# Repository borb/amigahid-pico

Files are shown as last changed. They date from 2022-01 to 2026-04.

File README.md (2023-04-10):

# amigahid-pico

please note: the interesting stuff goes into the [development](https://github.com/borb/amigahid-pico/tree/development) branch, so if main seems slow, check it out.

## introduction

amigahid-pico uses the rp2040 microcontroller (e.g. the raspberry pi pico) in a carrier board to attach usb input devices to a standard amiga without the need for a usb stack on the amiga itself.

it currently supports keyboards and mice and provides connection via the internal keyboard connector, the rj11/din socket on big-box amigas, and via the controller ports.

**this project is very much a work in progress.**

## **important note**

* current kicad files are for r5 pcb, pin mappings are not yet in the source tree! i have not yet generated this board as a pcb, but it is mostly identical to r4. the keyboard and controller port 1 are correct at time of writing, and will be fixed for the second controller port when the next prototype arrives.

* **always read the [errata](./doc/errata.md) section for the current pcb layout before deciding whether or not to build.**

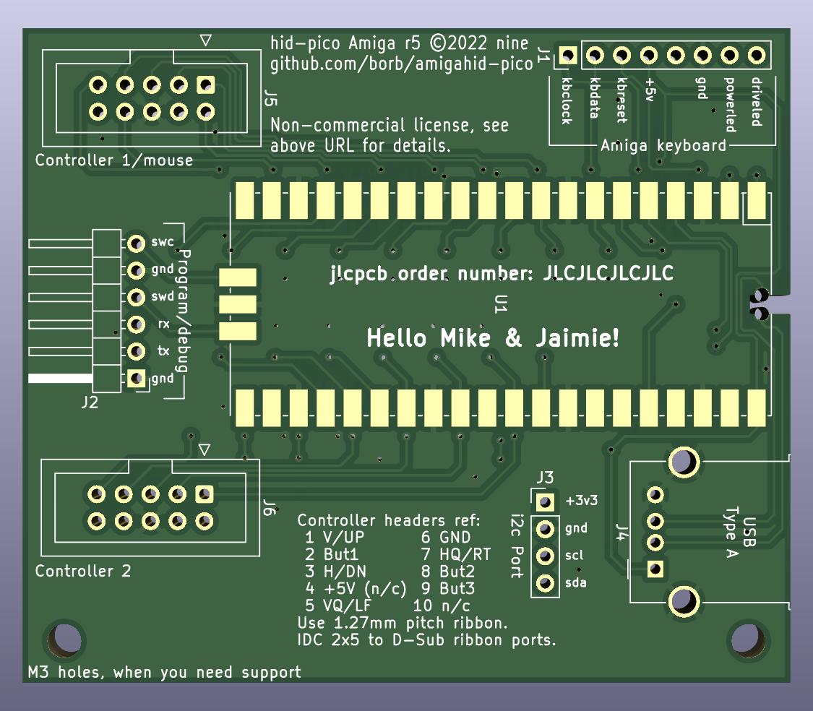
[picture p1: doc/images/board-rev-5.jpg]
rev 5 pcb


## documentation

* [installation](./doc/installation.md)
* [hardware](./doc/hardware.md)
* [errors in revisions (errata)](./doc/errata.md)

## history

this project is a rewrite of the [amigahid](https://github.com/borb/amigahid) project to the rp2040 microcontroller.

originally, after the retirement of the arduino adk board and shortening availability of the max3421e "usb host shield" for arduino boards, the need for a cheap, easy and continually available replacement was sought.

at first, the uhs mini via a level shifter seemed ideal, but significant issues were found convincing it to work with a variety of arduino boards.

the rp2040 made sense as a target because it is widely available, has sufficient physical connections and is powerful enough to meet multiple needs.

## what is the latency of this?

i have not measured the latency, but the keyboard signals are sent out the moment they are received on the usb bus. the potential latency is likely fractionally longer than the amiga mcu but bear in mind the rp2040 is significantly faster than the standard amiga keyboard controller.

## roadmap

please see the issues tab on the [github repository](https://github.com/borb/amigahid-pico) for the current list of planned features. the tl;dr is:

normal:
* i<sup>2</sup>c display for config/status
* controller emulation
    * keyboard-based controller emulation (use udlr for directions?)
* flash memory-based configuration
* possible amiga-side control panel (using bidirectional controller port signals)
* rotary control simulation (for controlling gotek drives)

crazy talk:
* non-amiga support
* non-hidbp support
* analogue/paddle emulation
* fix some tinyusb issues (hotplug, timing-related instability)

## license

on the fence at the moment, but the current license choice is Eclipse Public License 2.0 (EPL-2.0).

## third party licenses

* µgui: this code contains 'µgui' by achim döbler; the license for this can be read at in the [display readme](./src/display/README.md)

## whuh... who?

nine <[nine@aphlor.org](mailto:nine@aphlor.org)>

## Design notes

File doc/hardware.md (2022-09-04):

# hardware

## how do i attach this to my amiga?

### a500

the standard board is designed to be mounted atop the amiga 500 keyboard header. mount a strip of eight 2.54mm pitch sockets with sufficient clearance from the nearby custom chips (cia, mostly). the drill holes are m3 - use some nylon supports to support the board and stop it flexing.

for other amigas, you will need to refer to your model's keyboard socket. instead of a socket on the underside, mount 2.54mm pitch idc pin strip to the top of the board and use dupont connections to attach to the amiga in your favoured manner. most amigas except for the a1000 (which uses an rj11 connector) use some form of din plug. the signalling is identical across the entire range.

the pcb has a key for signals; only kclk, kdat, power and ground are required. reset is not required for big-box amigas, which use clock to signal reset.

### a600/a1200

the amiga 600 and 1200 have a surface mounted keyboard mcu; until a design has been put together, you can tap kclk, kdat and reset from the chip (use an upturned plcc socket). find the pin information at [amigapcb.org](https://www.amigapcb.org/). please be **really** careful attaching to these machines.

attach these lines to the standard amigahid-pico header in the correct position.

### a1000/a2000/a3000/a4000/cdtv/cd32

the din socket (rj11 on the a1000) for these models should map the +5v, kclk and kdat. these models do not have a reset signal, instead they rely on holding kclk low for a period to signal the hard reset signal to the amiga.

map these pins to the corresponding signals on the a500 keyboard header on the amigahid-pico pcb.

## amiga 500 keyboard header

all signals are active low.

| pin# | signal | meaning  | notes |
|---|---|---|---|
| 1 | kclk | clock | |
| 2 | kdat | data | |
| 3 | /res | reset | issues a hard reset |
| 4 | +5v | 5v power | |
| 5 | nc | nc | not connected (often physically absent) |
| 6 | gnd | ground | though if powering arduino/avr from psu, may be able to use that ground line |
| 7 | pwr | power | provides power to keyboard power led to indicate amiga is on/audio filter status |
| 8 | drv | drive | indicates floppy drive activity |

7 and 8 are not connected to the pico in any way, so you may want to investigate another way of indicating floppy drive and power status.

## what about controllers?

please see the silkscreen for the short-term connection notes. the wiring guide is detailed there for simplicity.

using 2.54mm pitch idc pin plug (female type), insert 9 strands of 1.25mm pitch ribbon cable, aligning to pin one of the connector (usually with a red stripe on the ribbon), pressing with a vise or suitable ribbon cabling tool. using a ribbon-type d-sub, align pin 1 of the ribbon to pin 1 of the d-sub, and complete the attachment using the vise/ribbon cabling tool.

whilst the idc header has an interleave meaning the ribbon is ordered incrementally (1-2-3-4-5-6-7-8-9), the d-sub ribbon ordering goes 1-6-2-7-3-8-4-9-5; this is compensated for by the board design.

if you have a r2 pcb, i'm very sorry, you'll need to read the silkscreen and build a custom attachment, likely from dupont pins. i would strongly suggest switching to r4 or later.

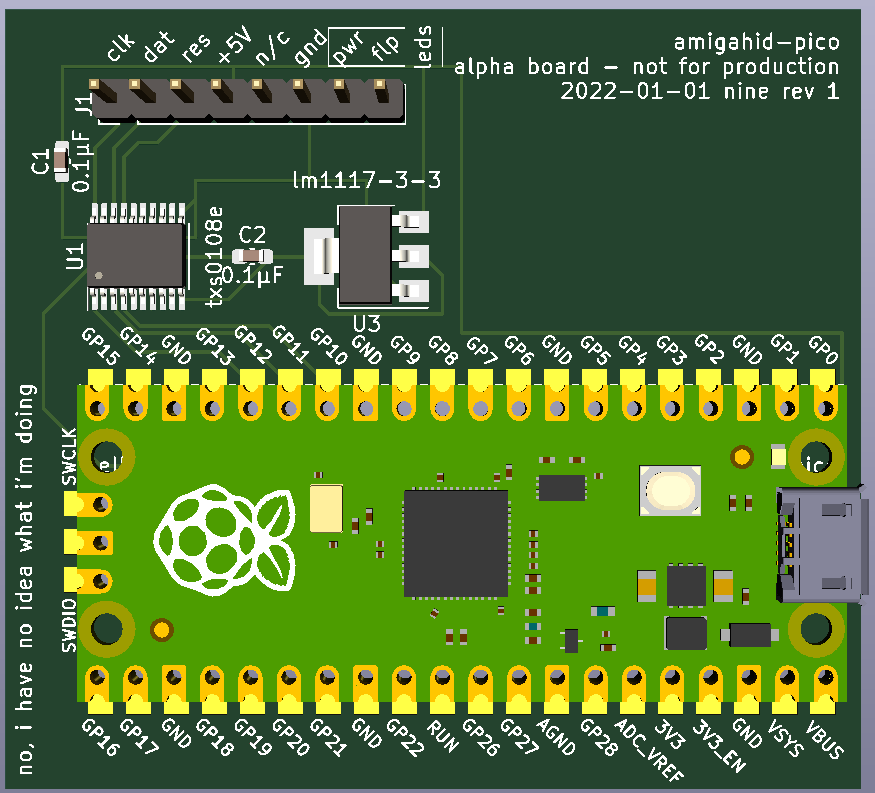
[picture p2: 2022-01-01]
doc/images/board-alpha-rev-1.png

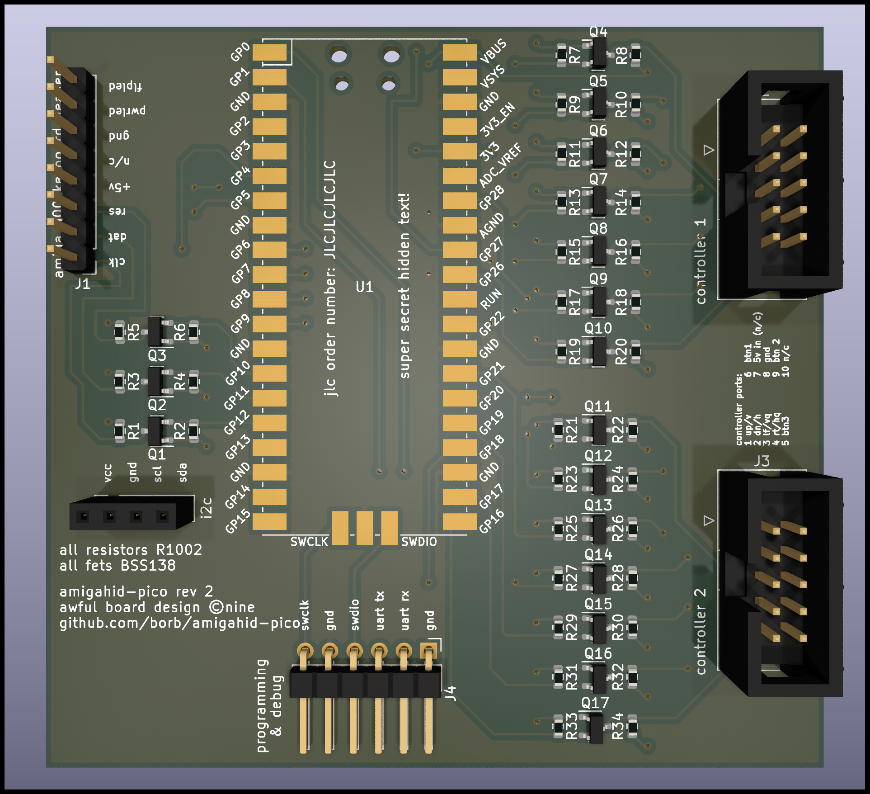
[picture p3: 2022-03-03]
doc/images/board-rev-2.png

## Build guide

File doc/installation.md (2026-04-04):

# installation

## configuration

the file [CMakeLists.txt](/CMakeLists.txt) has a small number of configuration options. the critical aspects of the build can be specified on the `cmake` commandline; you should not normally need to edit the [CMakeLists.txt](/CMakeLists.txt) file unless you are doing something outlandish.

## building the source code

prior to installation, ensure you have cmake, gnu make and gcc targetted to arm-none-eabi. you should be able to find these in debian. homebrew in macos has a cask for prebuilt gcc 10 binaries from arm. under windows, you're probably best off using wsl.

clone the repository. once cloned, you'll need to initialise the submodule for the pico sdk.

```shell
$ git submodule update --init --recursive
```

the tinyusb component of the pico-sdk has a lot of its own submodules so this could take some time.

when it's ready, start cmake off; you'll need to specify the board type you're using. if you omit it, you'll get a build for the default target, amigahid-pico standard pcb revision 4. this is akin to running:

```shell
$ cmake -B build/ -S . -DBOARD_TYPE=BOARD_HIDPICO_REV4
```

but you can also run this to get a revision 2 pcb build (the pin assignments are different):

```shell
$ cmake -B build/ -S . -DBOARD_TYPE=BOARD_HIDPICO_REV2
```

at present there are only two targets, revision 2 and revision 4. revision 3 users should not use the pcb as it has a faulty pin assignment which can spontaneously reset the rp2040 controller, so please do not use it.

you can also enable generation of debug symbols so as to use `openocd` and `gdb` to debug a running target over serial-wire debug (swd). to do this, add the parameter `-DCMAKE_BUILD_TYPE=Debug`, e.g.:

```shell
$ cmake -B build/ -S . -DBOARD_TYPE=BOARD_HIDPICO_REV4 -DCMAKE_BUILD_TYPE=Debug
```

a 'Release' build is generated by default.

then build:

```shell
$ cd build && cmake --build build/
```

see next section for installing on a pico.

## installing on a pi pico (or similar) board

for the simplest option, pick usb. swd is good for remote debugging and reprogramming without detaching devices.

### usb (bootsel)

take a powered down pico, hold the bootsel button and attach a micro usb cable. copy the `amigahid-pico.uf2` file from `build/src/` to the mounted usb storage volume. the pico will spontaneously disconnect, and when it comes back, it will be running the amigahid-pico code. disconnect usb and attach an otg adapter.

### serial wire debug (swd)

swd uses openocd to program the flash memory attached to the rp2040.

to use swd to install the firmware, see chapter 5 of [getting started with raspberry pi pico](https://datasheets.raspberrypi.com/pico/getting-started-with-pico.pdf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).

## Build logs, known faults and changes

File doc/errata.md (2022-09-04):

# errata

this project is still in the relatively early stages in terms of hardware design and i'm learning things like kicad as i go along. it's likely i'll make mistakes, so this section documents those mistakes.

## board revision 1

revision 1 was based around using the txs0108 bidirectional level shifter, which proved to be a mistake: whilst it worked for keyboard functionality, the voltage drop once connected to a controller port was so significant the amiga was held in reset. this would not have been an issue for big-box amigas as they have no dedicated reset line on the keyboard port, but it would have proved difficult for the amiga 500, 600 and 1200.

## board revision 2

revision 2 of the board was the first successful test. this will change in the near future as some quirks were discovered during assembly. the design was changed to be mosfet-centric using the bss138; this may change in future. long-term, i'd like to use an ic rather than a series of (at present) 17 mosfets, but i have not yet found a part which provides all of the desired features.

the pico is attached using castellated edges to pads on the surface. ensure the alignment is straight and flood the edges with solder, ensuring the solder makes contact with both the edge and the pad (check). buzz the attachment out with a multimeter to ensure it's worked and not shorted.

for the amiga 500, the keyboard connector can use 2.54mm pitch sockets on the seven pin header and attach directly to the motherboard, though for simplicity of placement you may want to use short dupont wires for attachment.

the programming & debug header provides serial wire debug and uart connections. you can program either via swdio or the usb port & bootsel button.

the four pin i<sup>2</sup>c header is suitable for the generally available ssd1306 displays to mount directly to, assuming the pin layout is identical. the display is not currently used but will be used in future versions.

attach a usb otg adapter to the pico's usb port. usb hubs are supported, but only at a single level. multiple mice and keyboards can be attached and used concurrently, allowing you to attach a keyboard for desk and one for remote usage (e.g. sofa).

the controller ports mapping will change after revision 2: the assumption was made that 2x5 pin idc connectors were wired the same way as d-sub 9-pin connectors, and this was wrong. the numerical wiring works 1-2-3-4-5-6-7-8-9 vs 1-6-2-7-3-8-4-9-5, making ribbon attachment difficult in revision 2. this will be changed in revision 3.

## board revision 3 (not in version control)

was a reworking of revision two but with the intention of being smaller and introducing a castellated edge for attaching to the usb test pads; this version was never put into version control and has the same idc numbering problem as revision 2.

## board revision 4

warning: don't build this version; it's just for testing.

sticking with the mosfet design, this version fixes the idc to d-sub pin wiring so a flat 1.27mm pitch can be used.

downside: there are vias beneath the pico's keepouts for the bootsel/ground/power test points. if your board manufacturer doesn't coat the vias with solder mask sufficiently then these could make contact with the test points. if this happens, either use some polyamide (kapton) tape or clear nail varnish to insulate the test points before mounting the pico.

erroneously, pin 30 (run) was attached as the horizontal/down line on the second controller port. as a result, h/down has been moved to 31, and v/up has been moved to 32 on revision 5.

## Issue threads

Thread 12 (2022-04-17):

Amiga configuration preference panel

borb, 2022-04-17:
Not yet sure if this makes sense if using i<sup>2</sup>c display (issue #5) and runtime configuration via keyboard hotkey (issue #6).

Gist is, button 1/2/3 are bidirectional pins on the Amiga side (they do go through a 74LS157 two-to-one line multiplexer), but can be used for bidirectional communication. Would need some form of attention-signal detection before beginning communication.

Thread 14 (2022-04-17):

Gotek control

borb, 2022-04-17:
As title suggests; control the Gotek navigation from the keyboard. USB HID has keys the Amiga does not, so this should be fairly possible.

i<sup>2</sup>c should be possible, or send pulses à la the rotary encoder mechanism. i<sup>2</sup>c would piggyback off of the display port but may have issues on Gotek-side with any displays attached there (or displays on the hid-pico side snatched by the Gotek). Rotary encoder pulses likely a safer mechanism.

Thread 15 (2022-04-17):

Send Amiga reset warning

borb, 2022-04-17:
I've pondered this for a while. I know that this behaviour is discrepant between Amiga models (Linux on my A1200 used to moan about it when ctrl-a-a was pressed). I don't actually know if the Amiga handles this; I've never probed the Kickstart ROM to work out it out. Can the 6502 code be read off of the keyboard MCU? That would be useful but I doubt it (most microcontrollers employ anti-theft mechanisms to prevent code being lifted from a device once programmed). I also don't have the kit for that.

However.

Anecdotally, dev docs refer to sending a reset warning keycode to the Amiga in order to get it to shore up its business before reset is asserted. If the reset warning isn't acknowledged, it's assumed the Amiga has gone to lunch and the reset pin (or clock low hold) is employed after a delay to ensure that the reset actually happens. This _should_ give the Amiga time to sync any filesystem buffers to disk before a reset occurs.

I don't actually know if in AmigaOS this ever occurs.

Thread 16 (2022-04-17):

Mouse wheel codes via keyboard interface

borb, 2022-04-17:
Wheel up/wheel down can be sent to the Amiga. OS 3.1 had support for this in the AmigaGuide renderer for Multiview, which is useful as a test. The codes are referred to as "NewMouse" standard [from the serial mouse driver in Aminet](https://aminet.net/package/driver/input/NewMouse12). I assume the codes were already referred to in a document somewhere prior to NewMouse implementing them. Because these codes reside above $80, they only need a single event transmission and not the typical down/up event of a keystroke.

It's possible that the mouse may need some form of mode switch much like the PS/2 era mice did to put them into 3 or 4 byte packet mode. This has not been tested.

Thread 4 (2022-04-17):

Tracking USB hub support in TinyUSB

borb, 2022-04-17:
The root repository uses the pico-sdk assigned tag from upstream TinyUSB, but in my working tree I build against [Ryzee119's TinyUSB multi-hub branch](https://github.com/Ryzee119/tinyusb/tree/multi-hub) which is currently [in a pull request](https://github.com/hathach/tinyusb/pull/1290) for upstreaming.

tl;dr: to use this, likely transient, tree in hid-pico will mean having to fork pico-sdk to repoint at the multi-usb branch, and that's annoying and temporary.

Right now, this issue exists purely to track the inclusion of multi-hub in upstream TinyUSB.

borb, 2022-09-04:
The pico-sdk (1.4.0) has not imported 0.14.0 yet, which is important for fixes to mousehid motion being jerky and multilevel usb hub support.

As a result, we now load our own tinyusb. This is in main as of 9641b7586c963452d354f7d5ce13c67297ff7321. Closing.

Closed 2022-09-04.

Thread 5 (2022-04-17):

i2c display support

borb, 2022-04-17:
Add i<sup>2</sup>c display support. This will allow the user to:

* track device connection status
* see operation status
* debug/diagnose without serial at a glance
* access config menu (when added)

Current target is 128x64 SSD1306 display. Initial tests with some library code have proved unreliable, as the font was small but switching to a larger font caused rendering issues. Suggest porting the code from flashfloppy's stm32 target to the rp2040 i2c layer.

borb, 2022-10-31:
Completed.

Closed 2022-10-31.

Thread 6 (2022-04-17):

Runtime configuration

borb, 2022-04-17:
Add support to change configuration during runtime rather than at build time. It would be annoying to assemble, compile, deploy and fit a board only to find, for example, right-Amiga is mapped to right-GUI rather than menu since that would impede Amiga rebooting.

Add a menu (dependant on display) and store configuration in flash. Load that configuration on power up. Allow for config to be reset.

Depends on issue #5.

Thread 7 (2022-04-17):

USB Type A socket

borb, 2022-04-17:
Add a USB type A socket. This can be done by either:

* connecting to the micro-USB port and providing a type A socket; hacky but stable
* attaching to test points beneath the micro-USB socket and running to a type A socket

borb, 2022-04-17:
Added in revision 4 (see 65ffd97fab697f31d4ec6cc0d69d6c9d1e991e65). Awaiting PCB delivery to test.

borb, 2022-04-20:
Protos arrived today. Didn't specify castellated edges, but the finish is easily acceptable (the aperture is super tiny though, so this is either a hot air or tiny tip job. Had to trim some hanging via plating with a scalpel. Test pads line up ok, solder mask looks suitable. Think this might work ok.

Will assemble tomorrow.

borb, 2022-04-21:
Ok, it works.

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

I'm keeping it external whilst I probe around the pins to see what's firing where, but everything works. Still need to move the ground plane via, which is in the Pico's keepout area. But success.

rfuest, 2022-04-21:
Nice, the USB A connector looks so much better than an OTG adapter. I think I should build one.

borb, 2022-04-21:
> Nice, the USB A connector looks so much better than an OTG adapter. I think I should build one.

I have more boards than I am going to use in this production run. Would you like a couple of samples sent to you?

rfuest, 2022-04-21:
Thanks for the offer. I'm not sure where you are located, but unfortunately it's often cheaper to order new PCBs for China than paying postage for PCBs.

borb, 2022-04-21:
Socket is working. Closing.

Closed 2022-04-21.

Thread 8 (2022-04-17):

Make keyboard LEDs work

borb, 2022-04-17:
Keyboard LEDs don't seem to work. The code was tried but commented out as it plainly didn't work, and suspect it has been responsible for TinyUSB stack crashes.

borb, 2022-04-17:
@rfuest has addressed this in PR #2.

borb, 2022-04-18:
Merged, tested, cllosing.

Closed 2022-04-18.

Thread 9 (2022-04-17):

Watchdog timer

borb, 2022-04-17:
Employ use of a watchdog timer. If the usual event loop doesn't poke the timeout register, the whole shebang gets rebooted.

Add the ability to turn this off via configuration (#6) since it could be irritating.

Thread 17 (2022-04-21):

lcont2_h connected to RUN input

rfuest, 2022-04-21:
In the latest schematic revision the `lcont2_h` signal is connected to `RUN` input (pin 30) on the Pico. This would reset the Pico on mouse movement or when the joystick is pushed back.

borb, 2022-04-21:
🤦

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

I really should have spotted that.

borb, 2022-04-21:
Okay, it's not as bad as resetting the Pico: the Amiga would have to pull back, and that won't happen because it's an output only and the Amiga keeps it at 5V; hence the other side of the fet will still be held at 3.3V.

So it's just a completely useless pin. Will fix; another revision on the way 😄

rfuest, 2022-04-21:
I was confused when I opened the issue and somehow thought that the controller connections were inputs :confused:.

rfuest, 2022-04-21:
Can we decide how this should be fixed in the next revision. I would like to change this in the PCBs I order and don't want to create yet another pinout variant.

The two easiest options are:
* Move `lcont2_h` to pin 32
* Move `lcont2_v` to pin 32 and `lcont2_h` to pin 31

borb, 2022-04-21:
The second option makes the most sense to me, since the first would mean having to route the second controller H line through another via in order to get to the same pin on the IDC connector, whereas the second just moves the fet connectors up a level.

Alternatively, I could produce another version this evening (I need to go and put my children to bed first) and if it passes your visual inspection, go with that version?

borb, 2022-04-21:
Actually, looking at the pcb layout, I'll just change the top-side tracks from the vias to the pads; the vias can remain where they are for bottom-side simplicity, and the top side can move over.

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

And I'll fix this as well. And remember not to turn the visibility of User.Drawings off whilst placing vias in future.

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

rfuest, 2022-04-21:
> Alternatively, I could produce another version this evening (I need to go and put my children to bed first) and if it passes your visual inspection, go with that version?

I think I'll create my own version of the PCB. I want to rearrange the keyboard and joystick connectors to one side of the PCB. And I'll probably try to use a 4 layer PCB to make the power/ground routing a bit easier. By using a 4 layer PCB it's also possible to use a controlled impedance trace for the USB connection, which is probably not necessary for the short USB 1.1 run, but it makes me feel better :wink:.

borb, 2022-04-21:
> > Alternatively, I could produce another version this evening (I need to go and put my children to bed first) and if it passes your visual inspection, go with that version?
>
> I think I'll create my own version of the PCB. I want to rearrange the keyboard and joystick connectors to one side of the PCB. And I'll probably try to use a 4 layer PCB to make the power/ground routing a bit easier. By using a 4 layer PCB it's also possible to use a controlled impedance trace for the USB connection, which is probably not necessary for the short USB 1.1 run, but it makes me feel better 😉.

You sound like you know what you're doing 😄 Would very much appreciate seeing this done properly as well!

rfuest, 2022-04-21:
Have you decided on a license for the PCB project yet? To my very limited legal/licensing knowledge, the non commercial clause on the PCB doesn't match with the EPL mentioned in the README.

borb, 2022-04-21:
> Have you decided on a license for the PCB project yet? To my very limited legal/licensing knowledge, the non commercial clause on the PCB doesn't match with the EPL mentioned in the README.

My knowledge is limited in this area also.

All I particularly want to avoid is the swathes of overpriced stuff being sold at a markup on eBay and elsewhere, especially since this is a fairly simple board. I've seen some other projects of similar ilk selling for ridiculous prices so I want to avoid that happening here.

My typical go-to would be creative commons, non-commercial, sharealike with attribution.

Closed 2022-04-21.

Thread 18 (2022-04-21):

PCB issues

borb, 2022-04-21:
Two things:

- Fix typo - "commerical" should be "commercial"
- Move ground plane via out from beneath pico keepout

borb, 2022-04-21:
Fixed in last two commits.

Closed 2022-04-21.

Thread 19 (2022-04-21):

LED pins

rfuest, 2022-04-21:
The README states that the user must find some other ways to connect the pin 7 and pin 8 leds. IMO it would be useful to provide some option to use these signals. Here are some options to use them:
* Empty LED and resistor footprints on the PCB that can be populated if required
* A resistor on the board and two 2 pin 2.54mm pin headers to connect PC case style LEDs
* Connect the LED pins to the unused Pico inputs
  The LED state could be displayed on the OLED. The connection would require level shifting from 5V to 3.3V. If an ADC input is used for the Power LED it would even be possible to distinguish between the filter on and off states.

borb, 2022-04-22:
This is something I'm personally going to need to manage as the Checkmate case will need to display power state, and possibly drive state as well. Ultimately I'd like this to be a pass through for my own (and other people's) purposes, but feeding one or both into the Pico is certainly a possibility.

User @M1kerochip has suggested displaying the floppy status on, for example, the scroll lock LED, but I think I'd like to avoid that if possible - it has benefits for remote-operated Amigas but beyond that, I'm not an enormous fan.

Three of the four unused GPIO pins at the bottom are personally earmarked for rotary encoder emulation - it uses the same encoding method as a single ball-mouse axis so isn't a huge stretch to implement, and could relieve my complaints about using the microswitches on Gotek boards. However, if this was not to happen, then shifting the second controller pins down to the bottom pins to free up the ADC pins could be a possibility.

So, choices are:
- Into the Pico to display on the OLED
- Provide 3.3V/5V headers on the board for connecting to other LEDs

rfuest, 2022-04-22:
> Provide 3.3V/5V headers on the board for connecting to other LEDs

I'm not sure I understand what you mean by this. How would a 3.3V or 5V header help to connect LEDs?

borb, 2022-04-22:
> > Provide 3.3V/5V headers on the board for connecting to other LEDs
>
> I'm not sure I understand what you mean by this. How would a 3.3V or 5V header help to connect LEDs?

The case has two sets of cables; one for Amiga-type systems, where the power source is 5V. The other is PC-type systems, where the source is 3.3V. This affects what voltage stepping is done on the front panel.

borb, 2022-04-22:
...I'm referring to putting standard 2.54mm pitch headers on to voltage shift or pass through the Amiga's LED signal.

rfuest, 2022-04-23:
Sorry, but I still don't get it. Do we agree that the Amiga 500 and the amigahid-pico will still be connected with 8 pin connection that includes the LED signals? And that the amighid-pico PCB would contain two 2.54mm pitch pin headers to connect PC case LEDs for power and disk activity? But in this case the voltage wouldn't matter, because PC case LEDs are raw LEDs which require an external current limiting resistor.

borb, 2022-04-24:
> Sorry, but I still don't get it. Do we agree that the Amiga 500 and the amigahid-pico will still be connected with 8 pin connection that includes the LED signals? And that the amighid-pico PCB would contain two 2.54mm pitch pin headers to connect PC case LEDs for power and disk activity? But in this case the voltage wouldn't matter, because PC case LEDs are raw LEDs which require an external current limiting resistor.

Yes, that's what I'm trying to say.

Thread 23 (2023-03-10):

A600 Pins

Frogowitsch, 2023-03-10:
Hello,
I had no problem attaching the device to my A500, but the A600 is not so easy.
SMD soldering is no problem for me, but before I destroy the A600, where exactly do I need to solder the wires to ? A picture would be great, but if not possible, please give me a hint. My board is a rev 1.5, if you need this information.

borb, 2023-03-10:
Hello! Unsure which board revision you're using but great to hear from a user.

So, the A600 differs from the A500 since the keyboard controller is on the main A600 PCB rather than the keyboard assembly, as per the A500, A1000, A2000 and other big-box Amigas.

Directly below the keyboard membrane connector and immediately to the right is U13, the keyboard controller for the A600. This is probably marked 6571or 68HC05 (the latter was used in the A1200 & A600, but the former pretty much only in the A600).

Here's a very crude annotated photo:
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

hid-pico is setup to use open drain/active low, so the two controllers should cohabit safely without you needing to remove power from the 6571/68HC05, though if I'm honest, with both controllers connected (hid-pico will send an init sequence to the Amiga) I have _no_ idea if the init sequences will collide with each other. If yes, you might want to consider finding a safe way to remove 5V from the 6571/68HC05, or alternatively I could put a sleep into the code to pause before sending init to the Amiga to prevent collision.

I would suggest getting hold of a 44-pin PLCC socket and placing it over the top, then tapping the connections from there.

Be sure to test the signal points (DAT, CLK, RST) for 5V before attaching. And check ground obviously.

borb, 2023-03-10:
For reference: Use https://amigapcb.org to confirm any or all signals before attaching. The rev 2A is extremely similar to the 1.5.

Frogowitsch, 2023-03-12:
I checked all pins on this website, seems fine.
Now anything is connected, but it does not work. Where should I insert the sleep function ? Possible, that there is an init collision.
I checked the pins with my oscilloscope, dat, clk are fine, rst should also be.

Frogowitsch, 2023-03-12:
What I did not try is :
Can I only use the two joystick ports ? So I use the amiga keyboard and only convert mouse and joystick to usb. Is this possible ? Cant try atm, will be home in 4 days and would like to know :)

borb, 2023-03-13:
Hello again.

> _Can I only use the two joystick ports ? So I use the amiga keyboard and only convert mouse and joystick to usb. Is this possible ?_

This is possible, yes; the keyboard aspect is not mandatory, and as a result, you do not need to internally mount it if you just want the controller port access.

Joystick emulation hasn't been finished, and I have smatterings sitting in a git repository on my dev machine; I've been focussing on full-HID support for the mouse for a while and haven't yet finished that but it's closest to release.

What I'm saying is, mouse support is the only thing other than keyboard right now 😄

> _Now anything is connected, but it does not work. Where should I insert the sleep function ?_

It's worth checking that the USB keyboard has been picked up and that there's not some sort of issue. If you have a 3.3V serial adapter (FTDI or similar), then pins 1 & 2 on the pico provide serial, and by default, unless you've edited [`CMakeLists.txt`,](https://github.com/borb/amigahid-pico/blob/main/CMakeLists.txt) it's turned on.

If you've built one of my PCBs, then the serial pins are marked on IDC connector J2.

Another good indicator is turning on caps lock; if the LED illuminates, it indicates that the firmware is talking to the keyboard, and caps lock is triggered via command in the event loop.

If you want to increase the startup pause, look in [`keyboard_serial_io.c`](https://github.com/borb/amigahid-pico/blob/main/src/platform/amiga/keyboard_serial_io.c). Line 96 has a 1s sleep (1000 ms). Bump it to, say, 3000ms and that should cover it.

Out of interest, have you customised anything in [`CMakeLists.txt`,](https://github.com/borb/amigahid-pico/blob/main/CMakeLists.txt)? Just wondering if the issue is something else.

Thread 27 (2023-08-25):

Support keyboard and mouse in parallel

evlog, 2023-08-25:
Great project. Can I connect in parallel both a keyboard and mouse on the usb type c, input using a hub?

borb, 2023-08-27:
Hello; I'm not sure which USB type C input you're referring to - are you referring to the PCB design where a type A socket sits onboard adjacent to the micro USB port on the Pico board?

However, yes, a hub is supported. I do note that I have not had success using USB3 hubs. My A1200 uses an amigahid-pico board for both keyboard and mouse concurrently. The eventual design is intended to provide joystick support via controller conversion without having to plug/unplug any devices, hence the OLED display for configuring which devices are routed to which ports. Furthermore, the mouse wheel codes need to be sent to the keyboard controller (two keycodes were reserved back in OS 3.1 for support at OS level without any additional software being installed). This will mean that using keyboard and mouse at the same time will offer scrollwheel support. The code is almost complete (on devel/mouse_hid_parser branch) and when I stop fiddling with my new A1200 board I will get it finished :laughing:

I have an in-development board which I have a prototype for; it adds a new IC, three electrolytic capacitors, three ceramic capacitors and three resistors but breaks out to two type A ports and a 9-pin IDC header suitable for dual USB panel mount connectors, the sort found on PC motherboards. At present I have only two ports populated but it's working well. I'm looking to push this up to the repository shortly.

borb, 2023-08-27:
If you are happy with this answer and are not having any problems with using two devices concurrently, please feel free to close this issue. Otherwise I am happy to use it to discuss any issues you may be having.

evlog, 2023-08-27:
Thank you so much for your support. Yes I meant connecting a hub on the type A socket and connect both keyboard and mouse. Good to know that this is supported. Superb! Thanks again.

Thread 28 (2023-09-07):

USB device enumeration occasionally silently fails

borb, 2023-09-07:
Sometimes, USB device enumeration does not occur on powerup. This event is usually silent, and no interrupt or assertion is raised by tinyusb. Unplugging and replugging USB devices has no impact on further enumeration and the hid-pico device needs to be power cycled (since there is no software reset trigger present) in order to restart the device and the USB stack.

Consider some form of watchdog event, e.g. if no devices are enumerated within 10s of initial startup, perform a device reset to attempt to trigger the stack to get into a usable state. Resetting the hid-pico software should have no impact on the host Amiga since the GPIO state will be retained during reset - all GPIO pins are set to input, open-drain with pullups disabled so won't accidentally assert reset in a restart situation.

Chandler-Kluser, 2023-09-08:
the first (and simpler) workaround can be taking the rp2040 RUN pin and attaching it to a PCB switch button so it does not need any firmware modification

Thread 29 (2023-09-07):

Caps lock state is inconsistent if system reset occurs whilst caps lock is enabled

borb, 2023-09-07:
If caps lock has been enabled (`caps_lock` global set to `true` in `src/platform/amiga/keyboard_serial_io.h`), and either the Amiga is reset from the machine-side or by use of the three-fingered-salute, then the caps lock state is inconsistent between the host and the controller. This would mean the caps LED is illuminated, and pressing caps lock will send a caps-release code (0x62 ORed with 0x80). Worst case scenario, this means pressing caps lock twice to get the keyboard into the intended state of being enabled, if required. Minor, I know.

This requires two fixes: ctrl-amiga-amiga should reset any stateful flags (in this case, only caps lock) when reset is asserted. Secondly, if a reset occurs from the Amiga-side, this should be detected and the stateful flags reset. This requires the hid-pico code to monitor. I am not sure how this is achieved (might need to scope the keyboard lines on a real Amiga keyboard to work this out). It's possible a pulse can occur on the reset line to indicate this. The rp2040 can be setup to trigger an interrupt if this occurs, but only if this theory proves to be correct.

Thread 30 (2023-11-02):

Simpler breadboard ciruit.

MrSVCD, 2023-11-02:
Hi
I was looking for a way to simplify the circuit for building on a breadboard pcb.
Specifically this: https://www.electrokit.com/en/product/experiment-board-breadboard-pcb-840-holes/
Can I use two 74HC/HCT/LS541 as level converter for a Amiga 500 or will this break the 500?

borb, 2023-11-02:
I haven't used that particular part, but I can't see why not. The A500 has a lot of 74-series logic inside it. As with everything, always check any levels with a meter before attaching to the Amiga itself. I have heard that the RP2040 is pretty tolerant of greater than 3.3V levels but I can't confirm if it would tolerate it long term; some work has been done using it to drive the a floppy disk drive, and that's 5V active low.

My only word of warning is that the current drain on the KBRESET using some 5V level shifters (e.g. TI TXS parts) is substantial enough that the voltage drops below a level sufficient to prevent the Amiga from randomly resetting when the current drops. It could be fixed with a pullup resistor on the reset line but I opted to use mosfets instead.

The same drain is also present on the potentiometer inputs on the controller ports if you're hooking those up as well (middle mouse and right mouse inputs are pot inputs for analogue devices).

Definitely interested in hearing your findings; I'd really like to simplify the design and stop using the array of mosfets & resistors

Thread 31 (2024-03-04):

Lantronics Spider KVM weird mouse issue

reinauer, 2024-03-04:
Hi,

I started using the amigahid-pico with a Lantronics Spider KVM. The

keyboard works fine but the mouse does not:

- Mouse is not shown as detected on the LCD
- Mouse moves somewhat when I move the host mouse, but only in one direction (all the way down, or all the way to the right)
- If I keep the right mouse button pressed, the mouse moves almost perfectly <-- this is the weird part
- Mouse buttons seem to work fine

Also, is CTRL-AMIGA-AMIGA mapped to anything?

borb, 2024-03-04:
Hello,

Depending on which branch you're using, the mouse connection count is incorrect. I strongly suspect the `main` branch is a culprit at the moment - I have the same issue with the hid-pico in my A1200. Once I get a little free time I'll put the mouse motion counter update into the branch which contains full support for HID report mode mice and merge it, because that fixes it. I'll try to do it this week but family life means I'm not usually free until ~10pm most evenings.

I've seen the motion issue as and it's really weird. I've also seen the issue where holding the right mouse button down causes motion to smooth out. I'm going to need to rewrite the mouse motion output because it's junk and fairly stupid. I've hacked it a couple of times and it's just really ugly.

As for reset: ctrl-leftgui-rightgui or ctrl-leftgui-menu will trigger the reset line, regardless of which branch you're on. However, as Claude reported, I'm not asserting the minimum pulse length of 50ms so as a manual hack, hold the keys long enough to keep it held. If you're connecting to an A2000/A3000/A4000, reset is handled by asserting the clock line for a period of time and it's picked up by a small circuit and translated into a reset signal. That's a fairly simple change and also needs to be done.

reinauer, 2024-03-10:
Ha, I am moving slow on this project as well. Thank you for your pointers. I switched to the development branch and the mouse started working a loooot better! Thank you for the suggestion.

As for asserting the clock line, is that something that could be done unconditionally? Or would this require adding a compile time option for A2000/3000/4000? Or even better, can the amigahid detect the Amiga somehow?

I'll play around with with this on my  A3000.

reinauer, 2024-03-11:
This is probably not the right way to fix the issue, but I can confirm that the following patch will make CTRL-LeftWin-RightWin reboot the A3000

```diff --git a/src/platform/amiga/keyboard_serial_io.c b/src/platform/amiga/keyboard_serial_io.c
index 4088427..637b7ee 100644
--- a/src/platform/amiga/keyboard_serial_io.c
+++ b/src/platform/amiga/keyboard_serial_io.c
@@ -201,6 +201,10 @@ void amiga_assert_reset()
 {
     // ahprintf("[akb] *** RESET BEING ASSERTED ***\n");
     _keyboard_gpio_set(KBD_AMIGA_RST, LOW);
+    // Hold clock lo for 500us
+    _keyboard_gpio_set(KBD_AMIGA_CLK, LOW);
+    sleep_us(500000);
+    _keyboard_gpio_set(KBD_AMIGA_CLK, HIGH);
 }

 void amiga_release_reset()
```

borb, 2024-03-20:
That was the way I was intending to handle the reset line (I don't have a big-box Amiga to check with); I'll ask another user I know who uses this project to check it with their A2000.

I don't think there's really a point to making it configurable; at the very least, the .5s wait will help, since at the very least on my A1200 I frequently find that holding reset for too short a time will fail to reset the Amiga. Long term, once I've got the display menu+settings storage aspects working, I can make it a runtime configurable but certainly I don't believe there will be any ill effects using it on wedge Amigas.

I'll patch in the reset code now; it'll go into the development branch.

Should probably keep this issue open until development is merged down to main.

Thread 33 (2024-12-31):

Strange mouse movement issues

PlunderBunny2000, 2024-12-31:
I'm using an old USB Microsoft IntelliMouse with my freshly-made amigahid-pico and it mostly works, but I'm running into a couple of strange issues: horizontal movement is a little jittery normally, and when I left-click I can't move the mouse horizontally AT ALL. Is this in any way a known thing, or do you have any idea what might cause this?

PlunderBunny2000, 2024-12-31:
Additional info: Can confirm that the mouse works just fine on other PCs, and can confirm that the same problem occurs when I use the mouse on another amigahid-pico board

borb, 2025-01-01:
Hello; this may be similar to the mouse motion issue mentioned in #31 - could you try building the development branch rather than main and see if the behaviour is fixed?

borb, 2025-01-01:
For reference: I have seen this behaviour with that code as well, including an unusual preference for the mouse motion to move in diagonals. This was owing to poorly nested conditionals in [quad_mouse.c](https://github.com/borb/amigahid-pico/blob). I'm running development on the board attached to my A1200 and it's a lot smoother.

borb, 2025-01-01:
Oh, and before I forget: Can you confirm which revision PCB you are using?

PlunderBunny2000, 2025-01-01:
I'm using PCB Rev. 5, and I've solved one of the problems myself, just by switching from the IntelliMouse to a different mouse. I was looking around other places to try to solve this problem and saw a chart that mentioned that the IntelliMouse doesn't quite comply 100% with the HID standards?
So I thought maybe the mouse itself was responsible, switching to a new mouse fixed the horizontal jitteriness, although I still can't move the mouse horizontally when I have the left mouse button held down. That remaining problem definitely seems like it could be caused by poorly nested conditionals... I took a look at your main branch code but I am by no means a coder so I couldn't really tell if that's the problem, but I could understand if nesting of the conditionals might cause this behavior.
I'll try out the dev branch code and let you know if that clears things up both with the IntelliMouse and otherwise!

PlunderBunny2000, 2025-01-01:
Switching to the dev branch code fixed the last remaining problem, with having no horizontal movement while left-clicking. The movement does get a little weird when click-dragging, it feels like it doesn't want to move diagonally while click-dragging, but that's a more minor issue, everything is now at least functional with the dev branch code!

borb, 2025-01-02:
I have an IntelliMouse 5000 (the black laser variety) which I can give a try to reproduce the unusual motion; I'm not sure if it deviates from HID but for the most part, the version of amigahid-pico you're using uses the "hidbp" (boot protocol), which is a simplified architecture intended to be used by firmwares or operating systems prior to loading the "proper" HID driver.

devel/hid_mouse_parser is a branch currently being finished with a slight rewrite of the quadrature pulse mechanism but will culminate in moving to using HID reports rather than boot proto. It's been in progress for a long while now and I need the appropriate time and ability to clear enough desk space and power sockets nearby to get an Amiga running long enough to test it adequately :smile:  Soon, I really hope, because I'd like to move to controller support.

Keeping this issue open until development is merged into the main branch.

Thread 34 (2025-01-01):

See how possible it is to hook into Amiberry/WinUAE for testing purposes

borb, 2025-01-01:
Would be useful, especially given desk space at home, if I could either simulate an RP2040 (seen wowki, not sure if it's suitable for this purpose) or otherwise get a Pico to feed back into a simulated Amiga for testing some of the in-progress features without having to consider the PCB design.

This would help enormously with the joystick emulation, refining mouse motion and working out the intricacies of producing CD32-style button support.

WinUAE calls out to the CD32 code to obtain values related to CD32 buttons [here](https://github.com/tonioni/WinUAE/blob/master/cia.cpp#L1937) but this could be unhelpful since amigahid will need to pretend to be a serial shift register to get button reports into the hardware. Amiberry probably uses the same code given shared source heritage.

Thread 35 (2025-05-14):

Update pico-sdk to resolve failure to build using cmake 4

borb, 2025-05-14:
Builds failing with error:

```
CMake Error at CMakeLists.txt:1 (cmake_minimum_required):
  Compatibility with CMake < 3.5 has been removed from CMake.

  Update the VERSION argument <min> value.  Or, use the <min>...<max> syntax
  to tell CMake that the project requires at least <min> but has been updated
  to work with policies introduced by <max> or earlier.

  Or, add -DCMAKE_POLICY_VERSION_MINIMUM=3.5 to try configuring anyway.
```

This relates to the SDK stub which includes build files from the pico-sdk.

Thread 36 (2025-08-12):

Where does the D+ and D- go from the USB connector?

mamejay, 2025-08-12:
As the title states.  Checked the PCB and cannot see the data lines connecting to anything.

Am I missing something?

borb, 2025-08-12:
Hello @mamejay (and thank you @M1kerochip!)

This all depends on which D-/D+ you are referring to.

The small cutout beneat the Pico is intended to be filled so that it solders cleanly to the test pads on the rear of the Pico. Should look like this.

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

There is a position for a USB Type A header on the top side of the PCB, marked J4. The D-/D+ lines from the test pad run to this connector. End result should look like this:

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

As an alternative, you can fit 2.54mm pitched IDC header, four pin, and use a panel mount connector (the kind you get attached to PC motherboards for additional ports)

I'm sorry I didn't include a BOM in any of the PCB revisions. This was my first attempt at PCB design and is somewhat amateurish. I've been focussing on getting the MCU software improved with better support for mice and scroll wheels lately, so intend to revisit the PCB designs as well as producing something better suited to the Amiga 1200. At which point, I will include a BOM and better assembly instructions.

Please let me know if this answers your question.

mamejay, 2025-08-12:
Thanks so much!  I actually feel a little bit silly now.  I was trying to design a compact version of this to just do keyboard only, by using your kicad files and removing what I did no require.  Now I understand that the USB-A connection is just a duplicate of the onboard micro-usb of the PICO

M1kerochip, 2025-08-12:
https://github.com/wiretap-retro/A2000-USB-Keyboard-Adapter-RP2040

borb, 2025-08-13:
> I was actually looking for an external solution. I did check out wiretap's one but that uses a PiStamp which as not as readily available where I live and are a little pricey. I do like his solution though

All you require is clock, data and reset in that case; the level shifters will still be required but it should be simple enough.

I haven't had a change to revisit level shifting away from using discrete FETs and need to look in future into using an IC to provide sufficient signals, but I note that I did have trouble with using TXS0108 in that the voltage level on the reset line dropped too low and kept holding the Amiga in reset (or spontaneously resetting).

Do you mind if I ask which Amiga you are intending to attach this to?

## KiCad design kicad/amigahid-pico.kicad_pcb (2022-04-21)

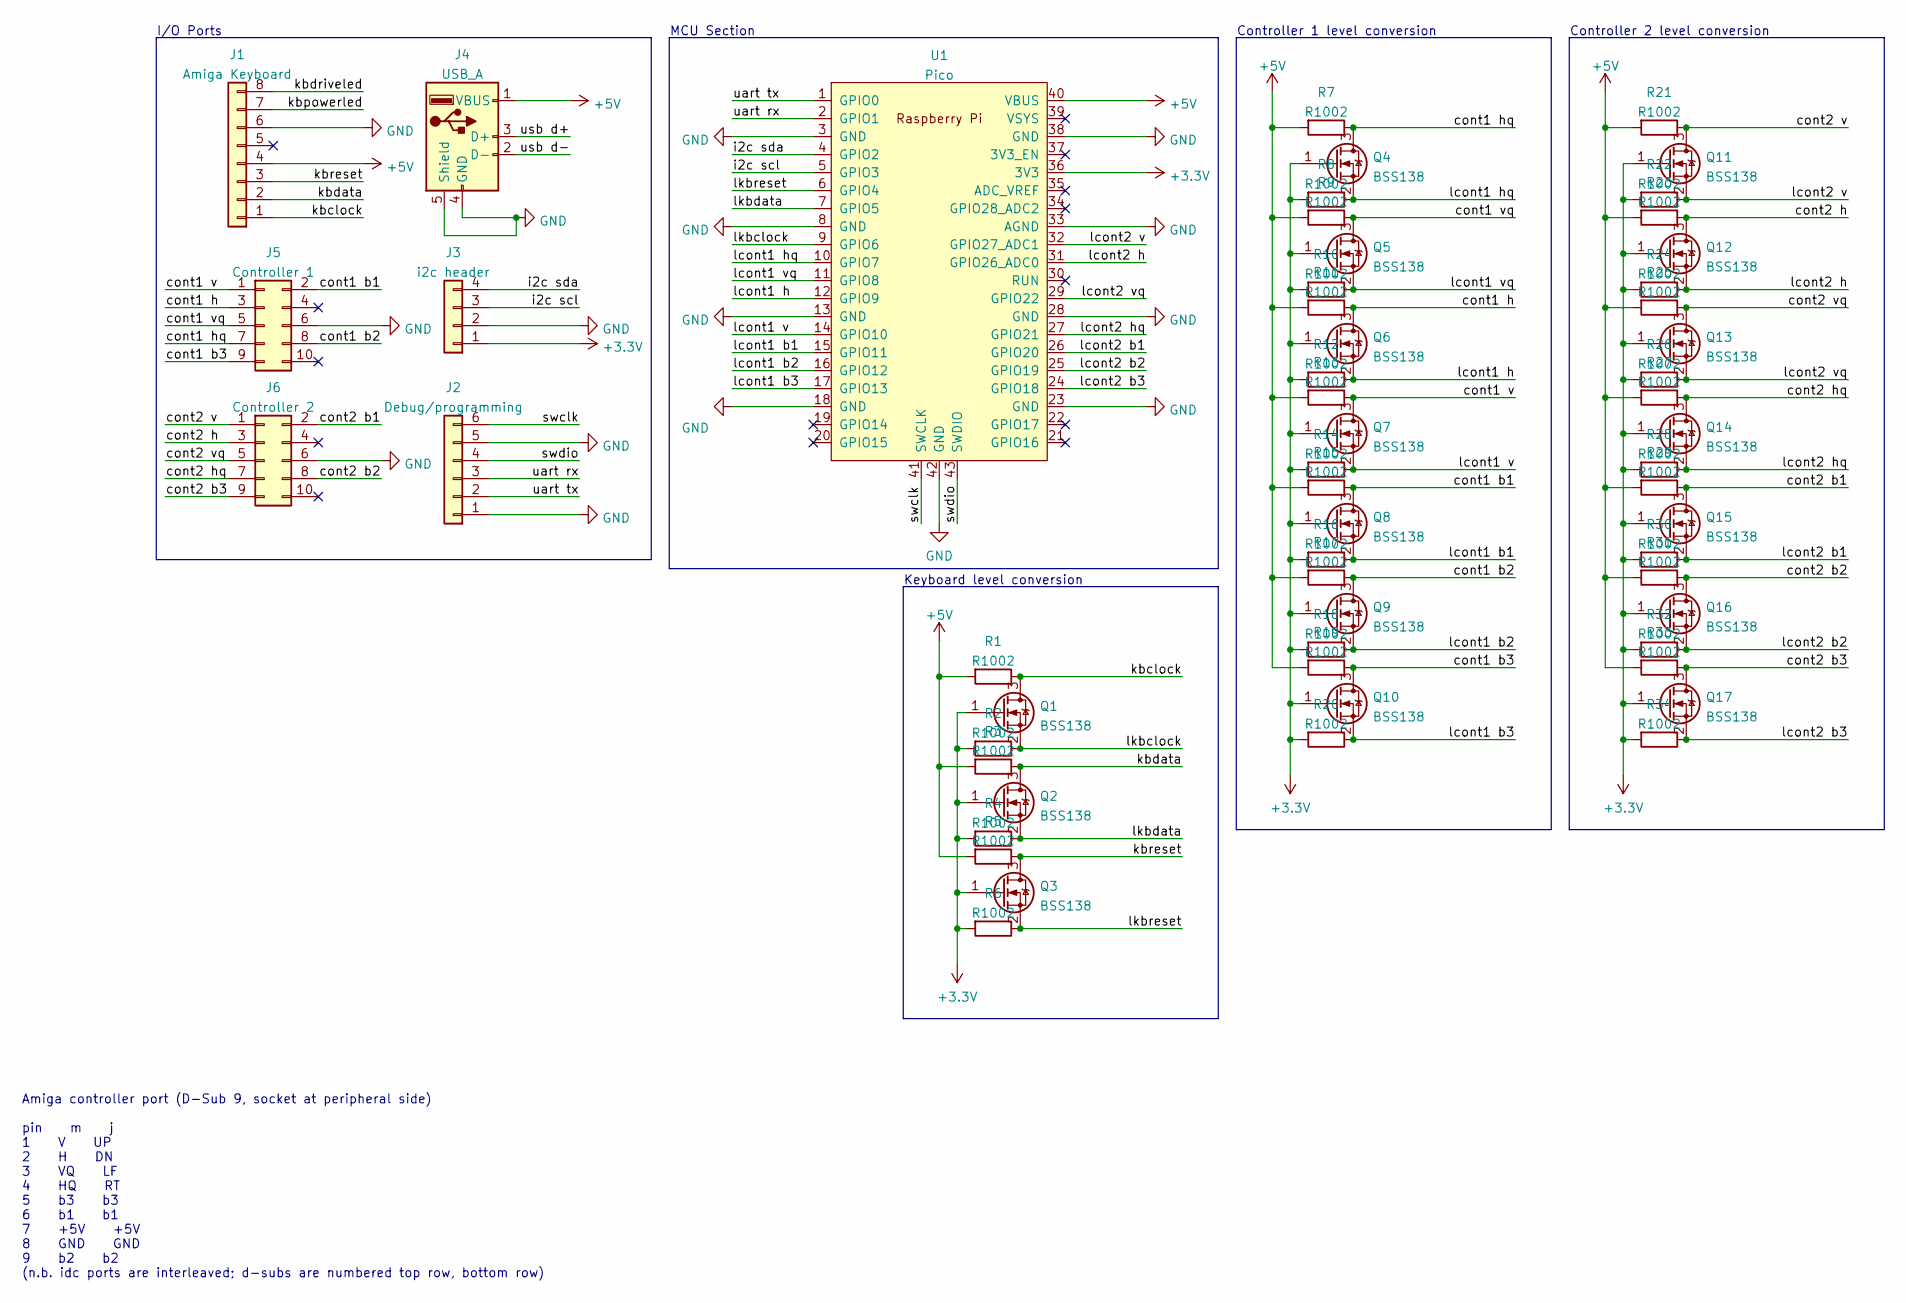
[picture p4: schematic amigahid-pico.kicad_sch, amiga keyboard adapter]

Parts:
J1: Amiga Keyboard; PinHeader_1x08_P2.54mm_Vertical
J2: Debug/programming; PinHeader_1x06_P2.54mm_Horizontal
J3: i2c header; PinHeader_1x04_P2.54mm_Vertical
J4: USB_A; USB_A_Molex_67643_Horizontal
J5: Controller 1; IDC-Header_2x05_P2.54mm_Vertical
J6: Controller 2; IDC-Header_2x05_P2.54mm_Vertical
Q1, Q2, Q3, Q4, Q5, Q6, Q7, Q8, Q9, Q10, Q11, Q12, Q13, Q14, Q15, Q16, Q17: BSS138; SOT-23
R1, R2, R3, R4, R5, R6, R7, R8, R9, R10, R11, R12, R13, R14, R15, R16, R17, R18, R19, R20, R21, R22, R23, R24, R25, R26, R27, R28, R29, R30, R31, R32, R33, R34: R1002; R_0603_1608Metric
U1: Pico; RPi_Pico_SMD_TH

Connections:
+3V3: J3.1, Q1.1 (G), Q2.1 (G), Q3.1 (G), Q4.1 (G), Q5.1 (G), Q6.1 (G), Q7.1 (G), Q8.1 (G), Q9.1 (G), Q10.1 (G), Q11.1 (G), Q12.1 (G), Q13.1 (G), Q14.1 (G), Q15.1 (G), Q16.1 (G), Q17.1 (G), R2.2, R4.2, R6.2, R8.2, R10.2, R12.2, R14.2, R16.2, R18.2, R20.2, R22.2, R24.2, R26.2, R28.2, R30.2, R32.2, R34.2, U1.36 (3V3)
+5V: J1.4, J4.1 (VBUS), R1.2, R3.2, R5.2, R7.2, R9.2, R11.2, R13.2, R15.2, R17.2, R19.2, R21.2, R23.2, R25.2, R27.2, R29.2, R31.2, R33.2, U1.40 (VBUS); also elsewhere on the board
/cont1 b1: J5.2, Q8.3 (D), R15.1; also elsewhere on the board
/cont1 b2: J5.8, Q9.3 (D), R17.1
/cont1 b3: J5.9, Q10.3 (D), R19.1
/cont1 h: J5.3, Q6.3 (D), R11.1
/cont1 hq: J5.7, Q4.3 (D), R7.1
/cont1 v: J5.1, Q7.3 (D), R13.1
/cont1 vq: J5.5, Q5.3 (D), R9.1
/cont2 b1: J6.2, Q15.3 (D), R29.1
/cont2 b2: J6.8, Q16.3 (D), R31.1
/cont2 b3: J6.9, Q17.3 (D), R33.1
/cont2 h: J6.3, Q12.3 (D), R23.1
/cont2 hq: J6.7, Q14.3 (D), R27.1
/cont2 v: J6.1, Q11.3 (D), R21.1
/cont2 vq: J6.5, Q13.3 (D), R25.1
/i2c scl: J3.3, U1.5 (GPIO3)
/i2c sda: J3.4, U1.4 (GPIO2)
/kbclock: J1.1, Q1.3 (D), R1.1
/kbdata: J1.2, Q2.3 (D), R3.1
/kbdriveled: J1.8
/kbpowerled: J1.7
/kbreset: J1.3, Q3.3 (D), R5.1
/lcont1 b1: Q8.2 (S), R16.1, U1.15 (GPIO11)
/lcont1 b2: Q9.2 (S), R18.1, U1.16 (GPIO12)
/lcont1 b3: Q10.2 (S), R20.1, U1.17 (GPIO13)
/lcont1 h: Q6.2 (S), R12.1, U1.12 (GPIO9)
/lcont1 hq: Q4.2 (S), R8.1, U1.10 (GPIO7)
/lcont1 v: Q7.2 (S), R14.1, U1.14 (GPIO10)
/lcont1 vq: Q5.2 (S), R10.1, U1.11 (GPIO8)
/lcont2 b1: Q15.2 (S), R30.1, U1.26 (GPIO20)
/lcont2 b2: Q16.2 (S), R32.1, U1.25 (GPIO19)
/lcont2 b3: Q17.2 (S), R34.1, U1.24 (GPIO18)
/lcont2 h: Q12.2 (S), R24.1, U1.31 (GPIO26_ADC0)
/lcont2 hq: Q14.2 (S), R28.1, U1.27 (GPIO21)
/lcont2 v: Q11.2 (S), R22.1, U1.32 (GPIO27_ADC1)
/lcont2 vq: Q13.2 (S), R26.1, U1.29 (GPIO22)
/lkbclock: Q1.2 (S), R2.1, U1.9 (GPIO6)
/lkbdata: Q2.2 (S), R4.1, U1.7 (GPIO5)
/lkbreset: Q3.2 (S), R6.1, U1.6 (GPIO4)
/swclk: J2.6, U1.41 (SWCLK)
/swdio: J2.4, U1.43 (SWDIO)
/uart rx: J2.3, U1.2 (GPIO1)
/uart tx: J2.2, U1.1 (GPIO0)
/usb d+: J4.3 (D+)
/usb d-: J4.2 (D-)
GND: J1.6, J2.1, J2.5, J3.2, J4.4 (GND), J4.5 (Shield), J5.6, J6.6, U1.3 (GND), U1.8 (GND), U1.13 (GND), U1.18 (GND), U1.23 (GND), U1.28 (GND), U1.33 (AGND), U1.38 (GND), U1.42 (GND)

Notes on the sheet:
Amiga controller port (D-Sub 9, socket at peripheral side) pin m j 1 V UP 2 H DN 3 VQ LF 4 HQ RT 5 b3 b3 6 b1 b1 7 +5V +5V 8 GND GND 9 b2 b2 (n.b. idc ports are interleaved; d-subs are numbered top row, bottom row)
MCU Section
I/O Ports
Controller 1 level conversion
Controller 2 level conversion
Keyboard level conversion

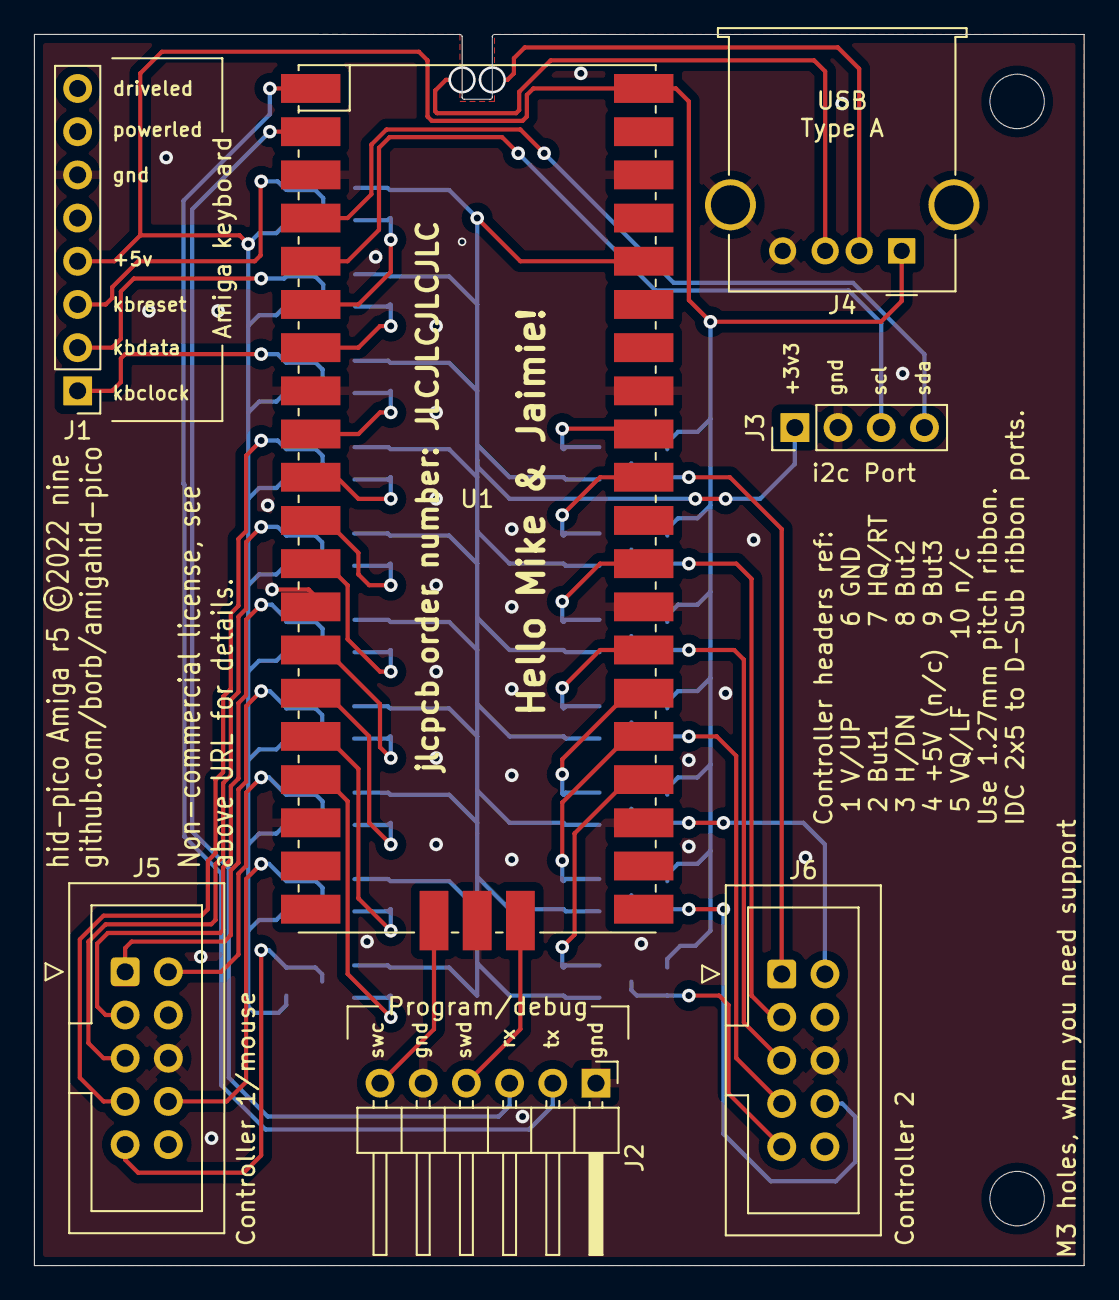
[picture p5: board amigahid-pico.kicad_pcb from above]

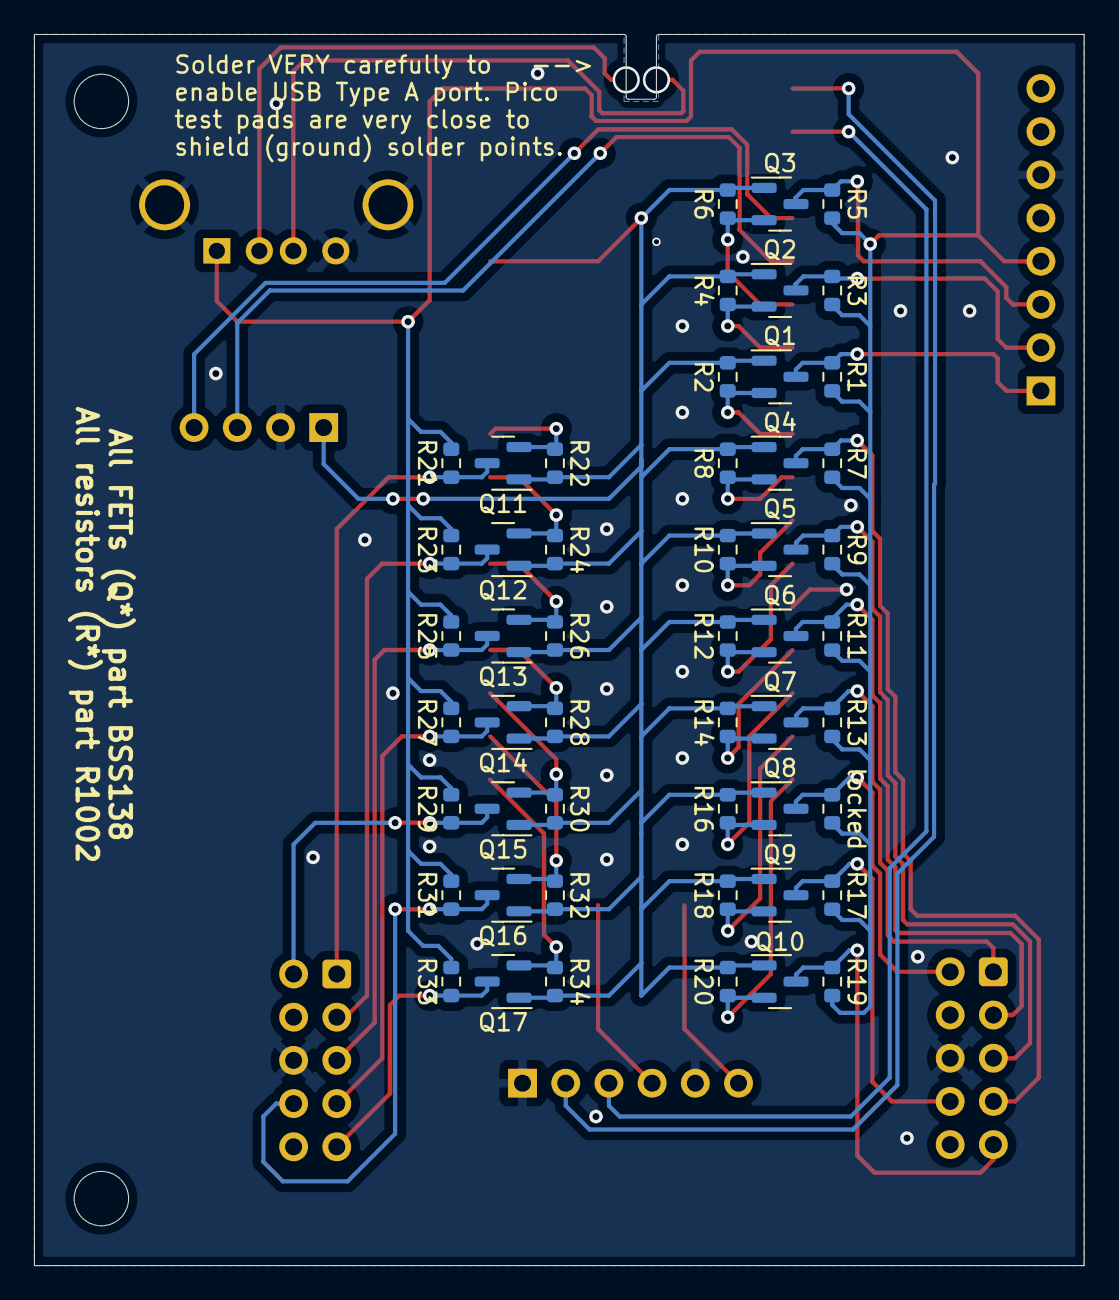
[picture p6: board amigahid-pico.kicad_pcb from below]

Board: 2 copper layers, 61.7 x 72.4 mm, 60 parts (51 on the bottom side), 43 nets.

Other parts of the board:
REF01, REF02: MountingHole_3.2mm_M3
locked: R1002; R_0603_1608Metric

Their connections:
+5V: locked.2; also elsewhere on the board
/cont1 b1: locked.1; also elsewhere on the board

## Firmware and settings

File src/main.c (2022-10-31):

/**
 * this file is part of amigahid-pico, (c) 2021 just nine <nine@aphlor.org>
 * please locate the full source at https://github.com/borb/amigahid-pico
 *
 * released under the terms of the Eclipse Public License 2.0 (EPL-2.0).
 * please find the complete license text at https://spdx.org/licenses/EPL-2.0
 *
 * main entry point for amigahid-pico.
 */

// these reside within the tinyusb sdk and are not part of this project source
#include "bsp/board.h"
#include "tusb.h"

#include "display/disp_ssd.h"
#include "platform/amiga/keyboard_serial_io.h"
#include "platform/amiga/quad_mouse.h"
#include "util/debug_cons.h"
#include "util/output.h"

#include "config.h"
#include "tusb_config.h"

// defined within usb_hid.c
extern void hid_app_task(void);

// main entry point
int main(void)
{
    // tinyusb board init; led, uart, button, usb
    board_init();

    // initialise the i2c controller and send the init sequence to the display
    disp_ssd_init();

    // say hello, trevor ("hello, trevor")
    dbgcons_init();

    // initialise the usb host stack on the rhport from tusb_config.h
    tuh_init(BOARD_TUH_RHPORT);

    // we're single arch right now, but in future this should hand off to whatever the
    // configured arch is
    amiga_init();

    // start amiga mouse emulation
    amiga_quad_mouse_init();

    while (1) {
        // run host mode jobs (hotplug events, packet io callbacks)
        tuh_task();

        // amiga keyboard service routine
        amiga_service();
    }

    return 0;
}

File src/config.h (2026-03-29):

/**
 * this file is part of amigahid-pico, (c) 2021 just nine <nine@aphlor.org>
 * please locate the full source at https://github.com/borb/amigahid-pico
 *
 * released under the terms of the Eclipse Public License 2.0 (EPL-2.0).
 * please find the complete license text at https://spdx.org/licenses/EPL-2.0
 *
 * hid-pico configuration
 *
 * PLEASE NOTE ALL PIN DESIGNATIONS ARE GPIO PIN NUMBERS - NOT PHYSICAL PIN NUMBERS
 */

#ifndef _CONFIG_H
#define _CONFIG_H

// the pico has an onboard led on gp25; use this as a default indicator
#ifndef INDICATOR_LED
#  define INDICATOR_LED PICO_DEFAULT_LED_PIN
#endif

#if defined(BOARD_HIDPICO_REV2)
#  define HAS_SCREEN
#  define HAS_KEYBOARD
#  define HAS_PORT1
#  define HAS_PORT2

#  define I2C_PORT      i2c0
#  define I2C_PIN_SDA   4
#  define I2C_PIN_SCL   5
#  define I2C_IRQN      23

#  define KBD_AMIGA_RST 10
#  define KBD_AMIGA_DAT 11
#  define KBD_AMIGA_CLK 12

#  define QM1_AMIGA_HQ  7
#  define QM1_AMIGA_VQ  6
#  define QM1_AMIGA_H   9
#  define QM1_AMIGA_V   8
#  define QM1_AMIGA_B1  22
#  define QM1_AMIGA_B2  26
#  define QM1_AMIGA_B3  27
#elif defined(BOARD_HIDPICO_REV4)
#  define HAS_SCREEN
#  define HAS_KEYBOARD
#  define HAS_PORT1
#  define HAS_PORT2

#  define I2C_PORT      i2c1
#  define I2C_PIN_SDA   2
#  define I2C_PIN_SCL   3
#  define I2C_IRQN      24 // this is tied to the i2c port being used so get the right one!

#  define KBD_AMIGA_RST 4
#  define KBD_AMIGA_DAT 5
#  define KBD_AMIGA_CLK 6

#  define QM1_AMIGA_HQ  7
#  define QM1_AMIGA_VQ  8
#  define QM1_AMIGA_H   9
#  define QM1_AMIGA_V   10
#  define QM1_AMIGA_B1  11
#  define QM1_AMIGA_B2  12
#  define QM1_AMIGA_B3  13
#else
#  error Board type has not been defined; check cmake command line
#endif

#endif // _CONFIG_H

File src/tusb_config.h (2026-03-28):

/**
 * this file is part of amigahid-pico, (c) 2021 just nine <nine@aphlor.org>
 * please locate the full source at https://github.com/borb/amigahid-pico
 *
 * released under the terms of the Eclipse Public License 2.0 (EPL-2.0).
 * please find the complete license text at https://spdx.org/licenses/EPL-2.0
 *
 * usb stack configuration; this file is included from the project source
 * by the tinyusb sdk so must be available within the include path
 */

#ifndef _TUSB_CONFIG_H
#define _TUSB_CONFIG_H

// rhport setting
#ifndef BOARD_TUH_RHPORT
#   define BOARD_TUH_RHPORT 0
#endif

// maximum speed permitted (which on a pico is usb 1.1)
#ifndef BOARD_TUH_MAX_SPEED
#   define BOARD_TUH_MAX_SPEED OPT_MODE_DEFAULT_SPEED
#endif

// should be defined by the pico board.h
#ifndef CFG_TUSB_MCU
#   error CFG_TUSB_MCU is missing; please check your configuration (ported to another board?)
#endif

#ifndef CFG_TUSB_OS
#   define CFG_TUSB_OS OPT_OS_NONE
#endif

// enable the host stack (if not explicitly enabled)
#ifndef CFG_TUH_ENABLED
#   define CFG_TUH_ENABLED 1
#endif

// max speed from board
#define CFG_TUH_MAX_SPEED BOARD_TUH_MAX_SPEED

#ifndef CFG_TUSB_MEM_SECTION
#   define CFG_TUSB_MEM_SECTION
#endif

#ifndef CFG_TUSB_MEM_ALIGN
#   define CFG_TUSB_MEM_ALIGN __attribute__ ((aligned(4)))
#endif

// usb descriptor buffer size
#define CFG_TUH_ENUMERATION_BUFSIZE 256

// supported devices & interfaces; tusb examples use a convention of multi-purpose
// constants where >0 may also mean multiple endpoints on a single device
#define CFG_TUH_HUB 8 // permit usb hubs (pico has a single port)
#define CFG_TUH_CDC 0 // no serial
#define CFG_TUH_HID 8 // keyboard/mouse/joystick; 4 endpoints maximum per device
#define CFG_TUH_MSC 0 // no mass storage
#define CFG_TUH_VENDOR 0 // not sure what this is but no anyway

// max device support (excluding hub)
#define CFG_TUH_DEVICE_MAX 16

// hid event buffer sizes
#define CFG_TUH_HID_EPIN_BUFSIZE 64
#define CFG_TUH_HID_EPOUT_BUFSIZE 64

#endif // _TUSB_CONFIG_H

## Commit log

2021-12-31 add caps lock and reset code
    [keyboard_serial_io.c]
2022-01-01 pcb proto - DO NOT BUILD (untested)
    [amigahid-pico.kicad_pcb, amigahid-pico.sch]
2022-01-01 add small note about the board design ground plane
2022-01-01 ha, missing static meant caps lock no worky
    [keyboard_serial_io.c]
2022-01-01 reverse pin order, as per kicad schema
    [keyboard_serial_io.c]
2022-01-01 fix the trinity check so two ctrl doesn't confuse it
    [keyboard_serial_io.c]
2022-01-08 fix fault causing keyup not to be sent to amiga
    [keyboard_serial_io.c]
2022-01-29 this is in usb_hid.c but it's not working
    [keyboard_serial_io.c]
2022-02-04 wip amiga mouse emulation (untested)
    this must be the fourth rewrite; committing as i think this might behave better. there may be issues with the pulse interval, which is currently 375us. 37.5ms is probably a better timing, but i want to thoroughly test this first.
    [main.c, quad_mouse.c]
2022-02-11 fix mouse motion. it works!
    [quad_mouse.c]
2022-02-15 whilst i'm routing the pcb, commit this; maybe sub to change
2022-02-27 update schematic to use fets, txs0108 not suitable (+)
    the txs0108 doesn't do well with capacitive loads, so the reset line
    keeps dropping too low (around 3.8v or below); the knock-on effect is
    that the amiga keeps resetting itself but moreover controller ports do
    not work correctly (if at all), and the keyboard behaves erratically
    (though the keycodes get through, the voltage levels are too low to
    match spec).
    tried with txb0108; effect was similar, but actually worse in many ways.
    the first production board revision will use FETs, but this may change
    if i find a more suitable logic level converter - i don't particularly
    want to give up the bidirectional nature of many of the lines becaus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
    [amigahid-pico.kicad_pcb, amigahid-pico.kicad_sch, amigahid-pico.sch]
2022-03-03 change resistor footprints to 1608 (metric)
    [amigahid-pico.kicad_sch]
2022-03-03 add rev2 pcb design (ALL THE VIAS)
    [amigahid-pico.kicad_pcb]
2022-03-03 update board picture
2022-03-15 don't raise output; set dir=in and let amiga do it
    cryptic short message, but by not raising the output to high level we're
    not actively sending a high signal, instead relying on the amiga doing
    so. ultimately, with the current mosfet-based design, it doesn't matter
    a great deal: either side of the voltage conversion uses a pullup, so a
    current is raised regardless, but the pico's drain to 0V (active low)
    will be unaffected.
    [quad_mouse.c]
2022-03-26 raise enum bufsize, device count. hubs work!
2022-03-28 add ssd1306 library from https://github.com/daschr/pico-ssd1306
2022-03-31 prevent mouse button events cancelling motion counters
2022-04-10 pcb rev 4
    [amigahid-pico.kicad_pcb, amigahid-pico.kicad_sch]
2022-04-10 r4 pcb update
2022-04-10 deadkeys: $0d for hid code $64, $2b for hid $32
    this fixes the missing backslash/pipe from the UK layout, and adds $2b,
    which is cut out of the large J-shaped return key on UK/US boards; some
    UK a600 and a1200 keyboards (possibly some late A500+) have this as a
    blank key, or deadkey.
2022-04-12 Update capslock LED
2022-04-21 add pin mappings for rev 4 board, make default
2022-04-21 add compile opt for board revision
2022-04-21 revision 5 pcb (fixes #17 and #18)
    [amigahid-pico.kicad_pcb, amigahid-pico.kicad_sch]
2022-04-21 readd m3 holes to board; update readme graphic
    [amigahid-pico.kicad_pcb]
2022-07-06 update pico-sdk to 1.4.0
2022-07-09 spelling mistake; aqm, not amq
    [quad_mouse.c]
2022-07-09 comment this out for a bit (it needs replacing with dma methods)
2022-07-09 remove a lot of debug noise
    [debug_cons.h, keyboard_serial_io.c, quad_mouse.c]
2022-07-11 fix issue with modifier map, causing rshift to output backtick
    [debug_cons.h, keyboard_serial_io.c]
2022-09-04 switch from pico-sdk's tusb to upstream 0.14.0; fixes mouse motion bugs
2022-09-25 add indicator led position; use pico default (since we use that)
2022-09-25 remove older ssd1306 things; prepping for dma code
2022-10-02 update with cmake stub from latest pico-sdk
2022-10-13 wip dma-driven i2c display; note: blocks for 100ms between ops!
    uses ugui for display writing. need to write isr-driven queue for i2c
    transactions.
    gh issue #5
    [disp_ssd.c, keyboard_serial_io.c, main.c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]
2022-10-17 fix linked list, turn off malloc mutex, tidy
    [disp_ssd.c, main.c]
2022-10-17 sample text whilst i work on positioning
2022-10-19 dbg counters case for unknown devices
2022-10-19 fix mismatching indentation on enum
    [disp_ssd.c]
2022-10-19 stub of check for device presence
2022-10-31 ssd1306 dma display support, clang-format config (#20)
    * add indicator led position; use pico default (since we use that)
    * remove older ssd1306 things; prepping for dma code
    * update with cmake stub from latest pico-sdk
    * wip dma-driven i2c display; note: blocks for 100ms between ops!
    * wip isr driven linked list (not quite working)
    * fix linked list, turn off malloc mutex, tidy
    * these @todos are redundant now
    * sample text whilst i work on positioning
    * use 5x12 pixel font positioned in a 5x16 area, y+2 offset
    * crlf -> lf
    * enable all warnings, warnings are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
    [config.h, disp_ssd.c, keyboard_serial_io.c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]
2022-10-31 output usb plug & kb data to i2c display
2022-10-31 Put usable data on the display (#21)
    * output usb plug & kb data to i2c display
2022-10-31 update to current tusb config
2022-10-31 Update to current tinyusb config standard (#22)
    * update to current tusb config
2023-03-21 Fix compilation on Ubuntu 22.04.2 LTS (#25)
    Compiler: (Ubuntu 22.04.2 LTS)
    gcc version 10.3.1 20210621 (release) (15:10.3-2021.07-4)
    Error:
    [100%] Linking CXX executable amigahid-pico.elf
    .../ld: CMakeFiles/amigahid-pico.dir/util/debug_cons.c.obj:(.bss.disp_write+0x0):
    multiple definition of `disp_write';
    CMakeFiles/amigahid-pico.dir/main.c.obj:(.bss.disp_write+0x0): first defined here
    .../ld: CMakeFiles/amigahid-pico.dir/display/disp_ssd.c.obj:(.data.disp_write+0x0):
    multiple definition of `disp_write';
    CMakeFiles/amigahid-pico.dir/main.c.obj:(.bss.disp_write+0x0): first defined here
    collect2: error: ld returned 1 exit status
2023-07-18 update pico-sdk to 1.5.1
2024-03-20 hold clk low for 500ms to reset a2k/3k/4k
    [keyboard_serial_io.c]
2026-03-28 Fix build for current version cmake & pico-sdk (#39)
2026-04-04 Release 0.1.1 (#42)
    * Add CI build & remove old devel prebuild (#40)
    * fix held ctrl-amiga-amiga
    move CLK set high to amiga_release_reset
    disable key sending whilst in reset - which would change CLK state
    * explain why keycodes sent not in reset, tidy formatting
    * fix docs on setting board type
    * fix held ctrl-amiga-amiga (#37)
    move CLK set high to amiga_release_reset
    disable key sending whilst in reset - which would change CLK state
    ---------
    [keyboard_serial_io.c]
2026-09-20 Prep for 0.2.0 (#47)
    * platform/amiga: fix quadrature mouse delta handling
    Keep mouse motion in 16-bit accumulators and preserve divider
    remainders between output batches.
    This stops small axis-only movement from being dropped before it
    reaches the Amiga quadrature genera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
    [debug_cons.h, quad_mouse.c]

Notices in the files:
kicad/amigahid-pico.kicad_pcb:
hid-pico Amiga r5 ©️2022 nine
